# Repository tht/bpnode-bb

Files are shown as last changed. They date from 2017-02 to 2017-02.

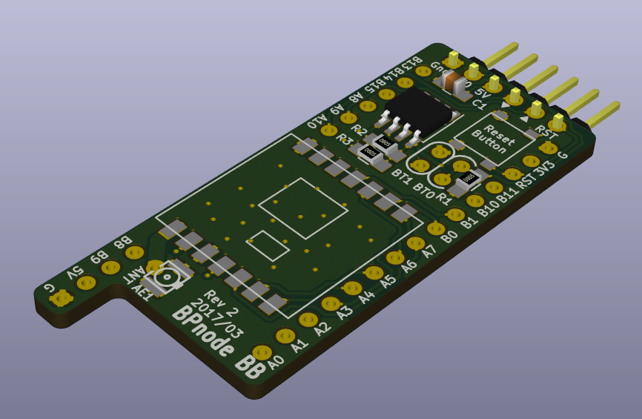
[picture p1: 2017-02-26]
images/rev1_top.png

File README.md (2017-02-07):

# *Blue Pill* Extender

There is a cheap, wildly available STTM3232F103C8T6 board out there. Because of it's shape and color it's called *Blue Pill* (BP). More details about this board can be found on [jeelabs](http://jeelabs.org/article/1649a/). There are *at least* two slightly different boards out there. This extension board is designed to match the BPs where the 2x03 pin header is next to `B11`, `B10` and `B1`. These are the boards where the USB connector is mounted in a cutout on the PCB. Other boards do have the USB connecter on top of the PCB and this 2x03 header is offset one pin – these boards will not fit nicely and need *creative* soldering as [shown here](https://cloud.githubusercontent.com/assets/148955/22704867/965d2520-ed69-11e6-9ae8-8ece3ff3e735.jpg).

The BP fits perfectly fine in a breadboard but it's missing the convenient programming headers for [SER+](http://jeelabs.org/article/1649f/) and some other features (see list below).

Thanks to the fantastic people over at jeelabs.org I was able to create this add-on board for the *Blue Pill* in KiCAD. This is how it will look like mounted on a BP.
BPE Mounted on a BP

## Features

* Programming header for programming the BP using a [SER+](http://jeelabs.org/article/1649f/) - including automatic reset of the target (BP)
* Area for mounting an RFM69-CW module
* Reset button
* Optimized for use on a breadboard

## Current State

Revision 1 is a little bit off-center but working perfectly fine.

There are some plans for the next revision of the board (see *Issues*). Some of them will probably become a completely different board as this one is meant to be used on a breadboard.

## Usage
The *Blue Pill Extender* (BPE) is mounted on top of an existing BP (label facing up). Make sure you solder the headers facing down to the BP first so it will fit into a breadboard before continuing here.

First prepare the BPE by soldering on the small resistors. The reset button is not required but may be helpful. Also add the RF module if you plan to use one. Make sure the RF module is not placed wrongly!

The 90° programming headers should be mounted from below (soldering on top) but they do work both ways.

Now remove the jumpers from the *BOOT?* pins on the BP and push the BPE on there. Make sure the 2x3 header of the *BOOT?* goes through the BPE and there there is still enough room to plug in an USB cable. Solder the 2x3 headers to the BPE. Now use some short wires (or leftover resistor legs) to connect all the outer BPE pins to the corresponding pins on the BP below – **DO NOT solder the antenna to the BP below!**

## References

* [Ser+ Programming Header](http://jeelabs.org/article/1649f/)
* [RFM69 CW Pinout](https://openenergymonitor.org/emon/sites/default/files/RFM69CW-V1.1_Hope_pinouts.jpg)
* [HyTiny Extender Layout](https://github.com/jeelabs/embello/blob/master/explore/1608-forth/tex/tex-v0.pdf)
* [BP Pinout](http://wiki.stm32duino.com/images/a/ae/Bluepillpinout.gif)

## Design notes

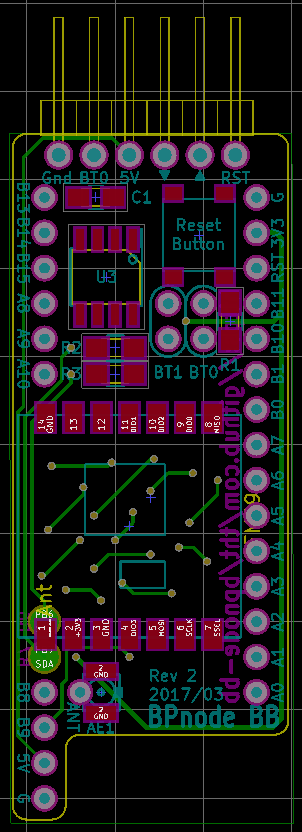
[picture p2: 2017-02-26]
images/rev1_board.png

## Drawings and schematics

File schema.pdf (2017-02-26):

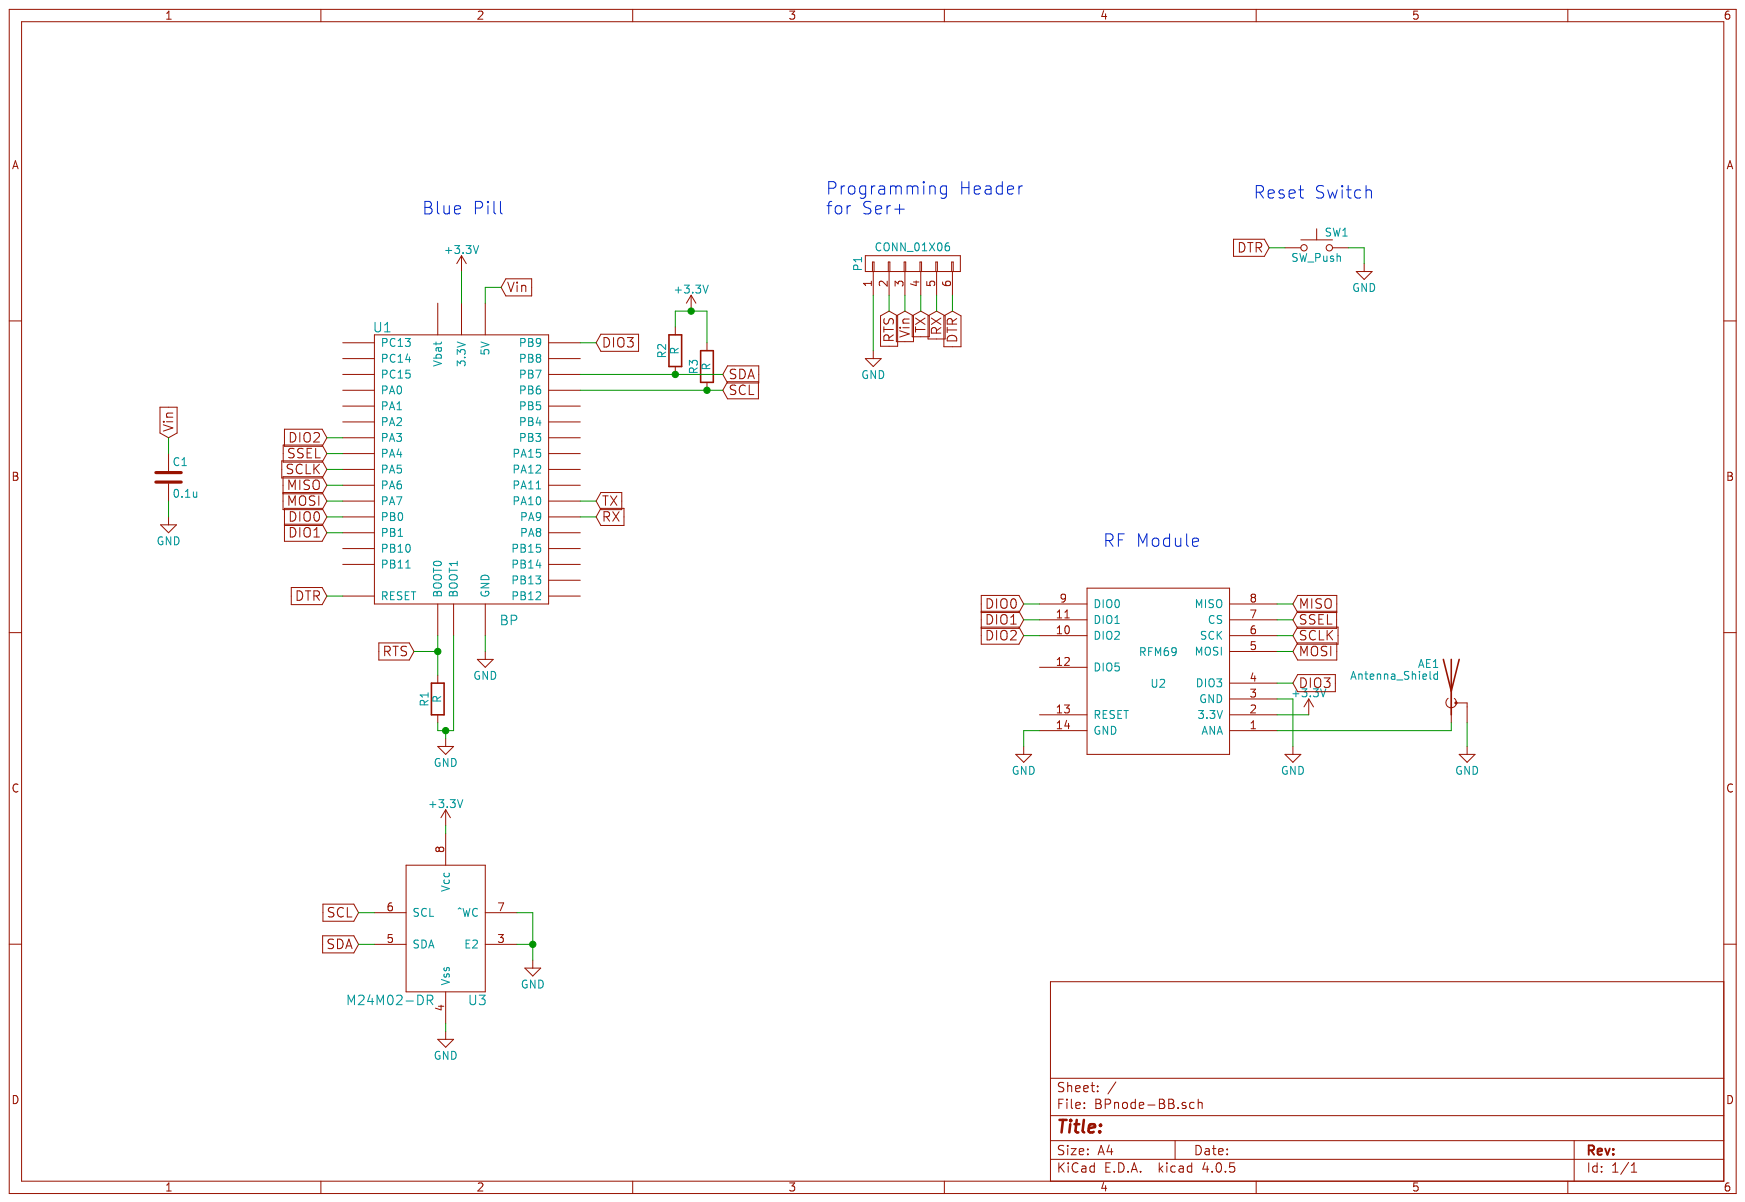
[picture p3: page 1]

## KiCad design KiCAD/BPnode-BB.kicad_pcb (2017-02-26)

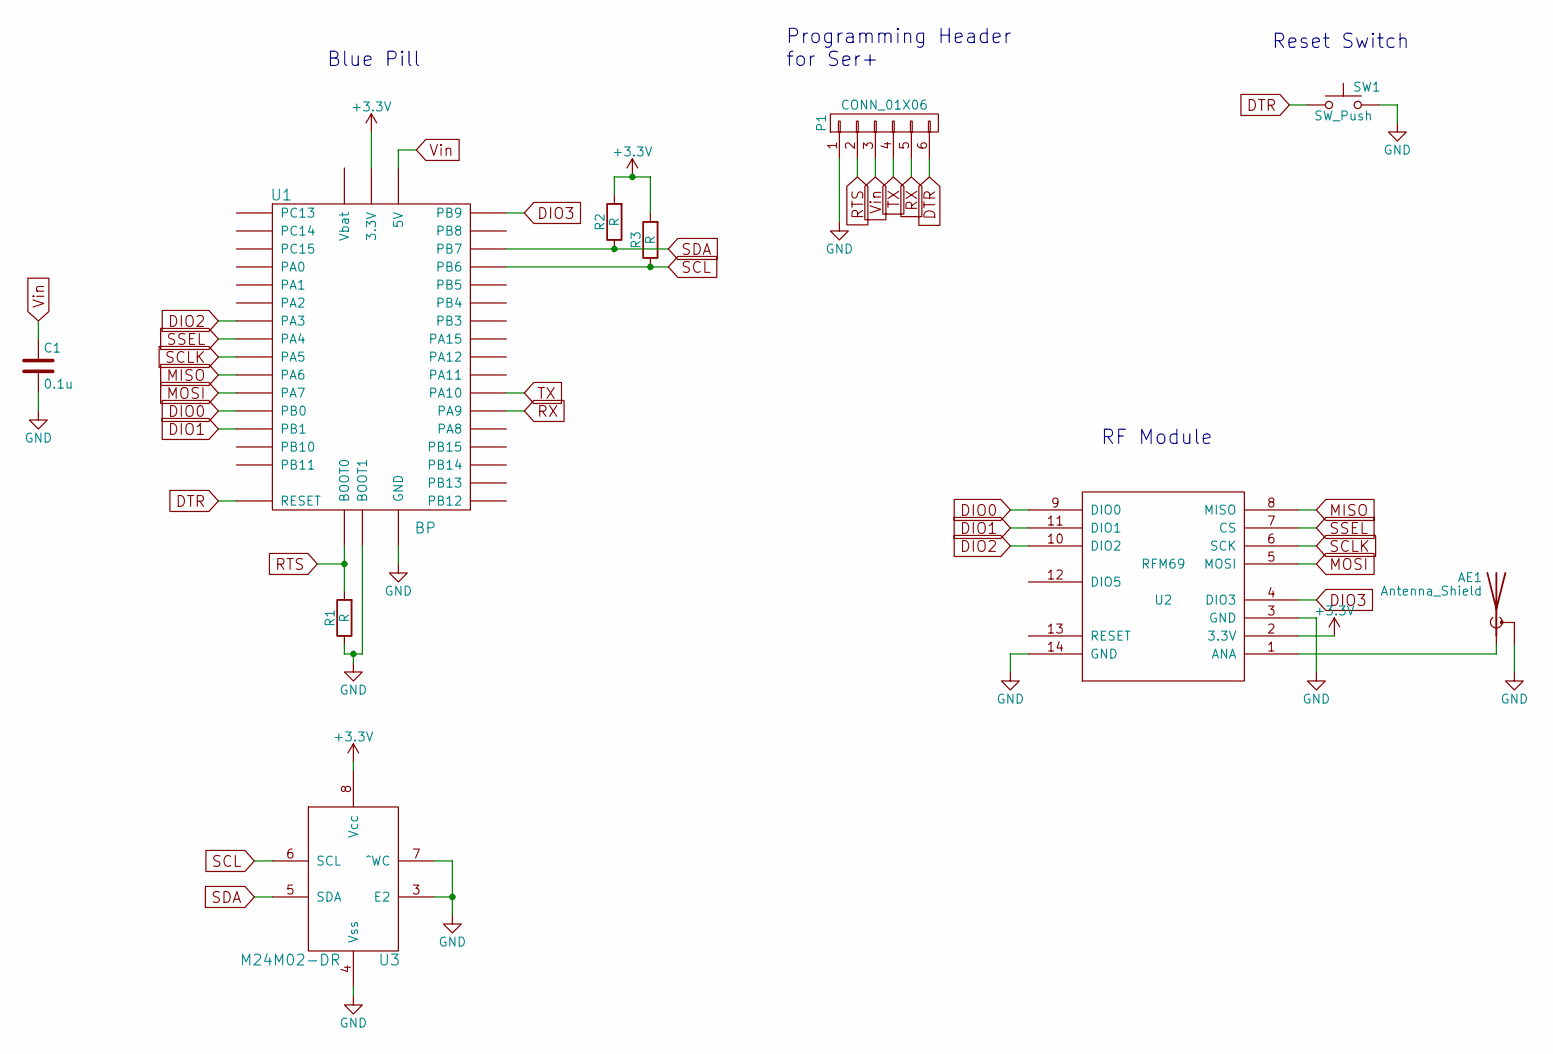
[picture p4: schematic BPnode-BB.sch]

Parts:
AE1: Antenna_Shield; U.FL-COAX
C1: 0.1u; C_0805_HandSoldering
P1: CONN_01X06; Pin_Header_Angled_1x06_Pitch2.54mm
R1, R2, R3: R; R_0805_HandSoldering
SW1: SW_Push; SMD_BUTTON
U1: BP; BLUEPILL-EXTENSION
U2: RFM69; RFM69CW
U3: M24M02-DR; SOIC-8_3.9x4.9mm_Pitch1.27mm

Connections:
+3V3: R2.2, R3.2, U1.3V3 (3.3V), U2.2 (3.3V), U3.8 (Vcc)
DIO0: U1.PB0, U2.9 (DIO0)
DIO1: U1.PB1, U2.11 (DIO1)
DIO2: U1.PA3, U2.10 (DIO2)
DIO3: U1.PB9, U2.4 (DIO3)
DTR: P1.6, SW1.1, U1.NRST (RESET)
GND: AE1.2 (Shield), C1.2, P1.1, R1.1, SW1.2, U1.G (GND), U1.PB2 (BOOT1), U2.3 (GND), U2.14 (GND), U3.3 (E2), U3.4 (Vss), U3.7 (^WC)
MISO: U1.PA6, U2.8 (MISO)
MOSI: U1.PA7, U2.5 (MOSI)
unnamed: AE1.1 (A), U2.1 (ANA)
RTS: P1.2, R1.2, U1.BOOT (BOOT0)
RX: P1.5, U1.PA9
SCL: R3.1, U1.PB6, U3.6 (SCL)
SCLK: U1.PA5, U2.6 (SCK)
SDA: R2.1, U1.PB7, U3.5 (SDA)
SSEL: U1.PA4, U2.7 (CS)
TX: P1.4, U1.PA10
Vin: C1.1, P1.3, U1.5V

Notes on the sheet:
RF Module
Reset Switch
Programming Header for Ser+
Blue Pill

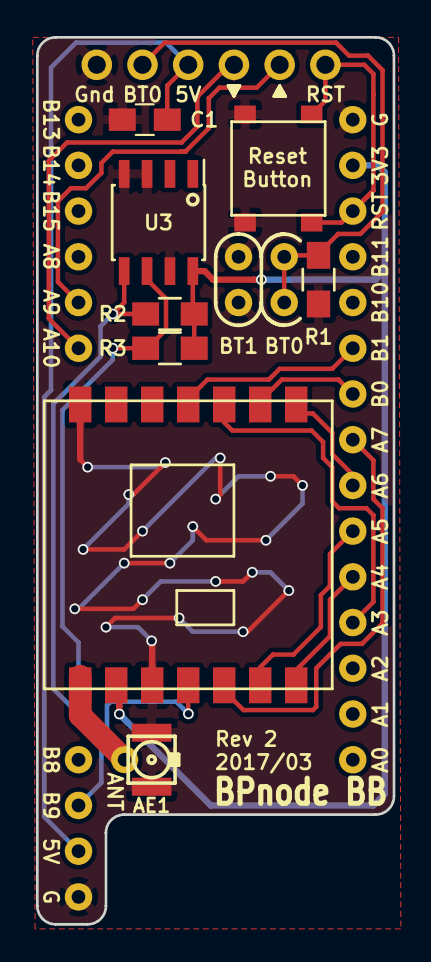
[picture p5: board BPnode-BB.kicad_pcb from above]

Board: 2 copper layers, 19.8 x 49.3 mm, 10 parts (0 on the bottom side), 18 nets.

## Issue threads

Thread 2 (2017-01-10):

Allow BP to reset the RFM69 module

tht, 2017-01-10:
Needs an additional pin, maybe some pull-up/down - unclear...

JohnOH, 2017-01-10:
Consider implications of using the STM reset pin.

Consider implications of detecting STM software reset since the STM Reset pin is pulled somewhere on software reset. I would be nice to have a latching LED if software reset happened. Pressing hardware reset would not set the LED, it would reset the latch.

JohnOH, 2017-01-12:
7.2.2. Manual Reset
A manual reset of the SX1231H is possible even for applications in which VDD cannot be physically disconnected. Pin 6 should be pulled high for a hundred microseconds, and then released. The user should then wait for 5 ms before using the chip.

Note whilst pin 6 is driven high, an over current consumption of up to ten milliamps can be seen on VDD.

JohnOH, 2017-01-17:
RESET on RFM is active high (ridiculous) - I can't tie them together

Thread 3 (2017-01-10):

Add a single AA boost chip / LDO regulator

JohnOH, 2017-01-10:
BP is a nice size for AA battery operation.
The existing regulator on the BP is frowned upon as being inefficient.

JohnOH, 2017-01-10:
Perhaps a LiPo charger instead, to act as  a UPS for an AC connected device.

tht, 2017-01-11:
The current *extender* is designed to be used on a breadboard. For standalone use there are some different requirements. For example we don't have to be on top of the BP and the size (specially the width) does not matter that much.

If this board works, we should start to collect requirements for another module - optimized for standalone use. AA power, LiPo charger and also easily accessible SPI and I2C ports are perfect candidates. I'll add a *label* to make sure de don't loose these ideas.

tht, 2017-02-09:
I will close this issue for now as this board has a different use-case and the BP is not optimized for low-power (battery) operation.

Closed 2017-02-09.

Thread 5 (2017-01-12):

Add a SPI Flash chip

JohnOH, 2017-01-12:
Similar to HyTiny extender. Other STM32 boards I have use a Winbond W25X16 which is 2M byte.

JohnOH, 2017-01-31:
Perhaps i2c rather than SPI to keep the radio clear.

tht, 2017-02-11:
Have you a recommendation for a commonly used I2C flash chip? My chunk drawer only *offers* some 5V devices…
I'll probably have to live on the back side of the board.

JohnOH, 2017-02-11:
I am not at home this weekend, I guess the 16Mb chip on the Jeelink would be a contender.

tht, 2017-02-11:
That's a Micron M25P16 SPI (0.80€ each). Looks like there aren't any I2C devices available with this capacity. The biggest one I could find is the STM M24M02 with 2Mbit for about 2.80€ each. So we have to decide between a 2Mbit I2C and a 16Mbit SPI. The board area does not allow for both.
Do you have a specific use-case in mind for this flash module?

Enjoy your day off!

JohnOH, 2017-02-11:
I imagined using it in a similar manner to the eeprom in the ATMega. I realise that a flash driver could be built (in C) but the cycle count is an order of magnitude less. The STM board I offer to you has an SPI eeprom on it, a W25X16. I was however concerned using SPI as my current approach in RFxConsole involves a scan of eeprom with each received pack as I store details of each node on the network. I don't know if SPI competition would be a problem.

JohnOH, 2017-02-11:
I also think that @jcw is on the i2c route for eeprom.

JohnOH, 2017-02-11:
Rereading everything, 2MB is more than enough for my currently perceived *needs*. Also, I thought you considered eeprom to be out of scope for this board.

tht, 2017-02-11:
Thanks for your feedback John. For me the small board size has priority but if there is a way to squeeze one mir IC on there, I'll do it.
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
As you can see the board area is not an issue. But now we need access to PB6 und PB7 for I2C. These pins are (of course) where the RF69 module is. I could add a smd solder pad on the bottom side where the RFM module is. I think this should still be possible to solder onto.

tht, 2017-02-11:
This is how it could work.
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
The small hole next to the SMD pads is the antenna connector. I'll move this one away when adding the U.FL connector.

jcw, 2017-02-11:
EEPROM mem over I2C is an order of magnitude slower compared to SPI flash. The F103 48-pin chip has 2 SPI buses, although that means more I/O pins needed, and IMO two devices on SPI is not that hard to support (even with interrupts: you can disable the ones from the radio while accessing flash).

FWIW, I want to drop flash again in the next HyTiny Extender revision - plan is to keep all persistent data on the USB host side. I guess it all depends on your use case.

Most flash chips are compatible, in terms of pinout. Would suggest using a _wide_ SIOC-8 footprint (5.3 mm), I think the narrow ones (3.9 mm) are starting to be phased out, definitely in larger sizes.

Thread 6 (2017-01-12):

Review CTS/DTR pin selection on FTDI interface

JohnOH, 2017-01-12:
If extender was mounted under the BP we have the option to collect the 4 pin group carrying GND/DCLK/DIO/3v3 in order to use DCLK & DIO similarly to HyTiny extender - see below:
https://github.com/jeelabs/embello/issues/35
This approach supports all the programming options via the FTDI port.

Extender on top would mean light pipes or holes to the see the LEDs - possible.

JohnOH, 2017-01-12:
Excessive enthusiasm on my part. The pin-out for a SER+ should be as above but the pin-in for a JNZ or similar needs to use BOOT0 and Reset.

JohnOH, 2017-01-14:
Review is still desirable since the FTDI port appears **able** to support the BMP firmware. The RX/TX and GND look good - not so sure about the DTR/CTS driving pins and their match to the *standard* BMP image. The 5v needs care to make sure it goes via a regulator on the target or is not activativated.

JohnOH, 2017-01-14:
Looks like these are the BMP pins:
TARGETBOARD     JC66_COREBOARD
 GND             GND
 SWDIO           PA4  *
 SWCLK           PA5  *
 POWER           3.3V from someplace with a common ground. Probably easiest to plug both boards in to USB

tht, 2017-02-09:
There are some good tutorials for converting a BP into a BMP ([hackaday](https://hackaday.io/project/19238-convert-stm32f103-board-to-a-black-magic-probe)).

For the moment this extension board is for BPs used as a programming *target* on a breadboard. IMHO this kinda conflicts with this issue and I don't want to include complicated parts like light pipes only to get the LEDs back.

Do I miss something here? Do you have a specific use-case?

JohnOH, 2017-02-09:
np, and thanks for the hackaday link.

JohnOH, 2017-02-11:
I appreciate that this board can operate as a node, subordinate to a Ser+ using its FTDI interface. I guess it can't operate as a Ser+ because of the choices made with regard to DTR and CTS/RTS.

I may be losing the plot here.

JohnOH, 2017-02-11:
Ser+ uses the SWD pins which are available on the tail end of the BP. Could use the two SWD pins to drive the DTR/RTS pins on a target node. TXD/RXD still derived from the FTDI header.

Closed 2017-02-09.

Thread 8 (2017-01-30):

Fix offset of rev1 board

tht, 2017-01-30:
The board is off-center – looks like 1.27mm. Should be fixed in rev2.

jcw, 2017-02-07:
There seem to be slightly different variants of the BP out there, see images.

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

JohnOH, 2017-02-07:
I think you may have a red pill layout on a blue PCB. I note that the USB connector is surface mounted rather than through the board. See http://www.stm32duino.com/viewtopic.php?t=117

JohnOH, 2017-02-07:
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

I fourteen units bought in two or three at a time from various chinese sources. They all have the the USB shield attached through the PCB rather than surface mount only.

tht, 2017-02-07:
Same here… about 10 boards, bought from two different sellers. All do have the USB socket mounted through the board. So this is the big difference, good to know. Thanks for investigating this issue. I will add a note in the `README.md`.

jcw, 2017-02-07:
Just to understand: my impression is that there is no difference, apart from appearance/dimensions?

jcw, 2017-02-07:
As I mentioned to Thomas in a private chat, I'm going to call mine the "twist and shout" setup - but it needs a lot of twisting and shouting to set up :) - haven't tried it out yet, it'll probably be 100% fine.

tht, 2017-02-07:
Your's is the one with *personality* :)

There are quite a few differences on these two boards. Labels are different, the USB connector is mounted different and the 2x03 header is not at the same place on the board. I think the board itself should be the same dimension when looking at your pictures. According to http://www.stm32duino.com/viewtopic.php?t=117 there is more like different LDOs and resistor/cap values.

JohnOH, 2017-02-08:
Perhaps we could physically remove four outer pins from the Blue Pill 2x03 header retaining only the path to the relevant GPIO pins. We could then drive these pins with 3v/GND derived from elsewhere on the Expander PCB. This would offer the opportunity of having four holes passing through the expander with connections in parallel such that a Red Pill and a Blue pill could both use the expander PCB soldering the appropriate two pins for that particular board.

tht, 2017-02-09:
Thats a great idea John. I'll most likely go this way for rev2 of the board. So it *should* fit on top of all red- and blue pills in red and blue coats.

3.3V and GND are available right next to these pins, so no problem to get these levels from other pins.

Only disadvantage is the loss in rigidity but I don't think this is a big issue. I will also try to Get hold of some long pin headers. Just snip off the top of these long headers where there is no hole in the extender board and connect all the others through.

tht, 2017-02-11:
I still have to fix the reset button's footprint and check if it's possible to add an U.FL connector but the offset *should* be fixed and this one is compatible with *pills* in all different colours.
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
I've added some holes which aren't absolutely needed. This should make it easier to mount it on extra long headers pushed through the BP and this adds-on board.

Closed 2017-02-11.

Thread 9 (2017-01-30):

Review reset button

tht, 2017-01-30:
The footprint is not compatible with the buttons I have. Review the footprint (or get other buttons)

Closed 2017-02-11.

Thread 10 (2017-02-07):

add diode in reset line from Ser+

tht, 2017-02-07:
Looks like it's working perfectly fine but there should be a diode in the reset line to make sure the BP is always able to do a clean reset.

jcw, 2017-02-07:
To clarify, although maybe it does not apply exactly to F103: on L052, a diode was needed to make reset 5V-tolerant and to support software reset, which cause the reset pin to be pulled low internally and act as an open-collector output. When tied to a stiff "1" logic level, software reset will fail.

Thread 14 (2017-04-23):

Rev2 PCB micro tweak

JohnOH, 2017-04-23:
Great work Thomas. I have only noticed one thing, based on a sample of one I think that the BT0/BT1 block could move half a millimetre closer to your reset switch to make the fit perfect. The same effect can be had by slightly bending the centre pair of BT0/BT1 pins a couple of degrees towards the processor. I don't have any Red Pill units and therefore can't comment on the implications there.

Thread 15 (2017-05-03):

I2C Eeprom Chip Enable

JohnOH, 2017-05-03:
E1 is unterminated and E2 is grounded. Since unterminated defaults to low the chip enable address bits are both 0.

JohnOH, 2017-05-05:
The *correct* datasheet only uses E2 as a chip enable.

Closed 2017-05-29.

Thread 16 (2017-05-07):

Access to BT0

JohnOH, 2017-05-07:
Ran into a problem whereby STLink, Black Magic Probe and Ser+/folie could not take control while running the STM32duino bootloader and [this](https://github.com/JChristensen/extEEPROM/tree/master/examples/eepromTest) sketch. Suspect code problems when running on STM32.

I needed to use BT0 to 33v3 to get back in control of the node. Used a jumper wire to the BT0 hole assigned to Red-Pill.

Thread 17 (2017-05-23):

Pull down resistor for BT1

JohnOH, 2017-05-23:
BT1 has significance in the STM32duino world as a mechanism to trigger perpetual bootloader. The general case of a high impedance pulldown on BT1 is flipped to 3v3 to enable the perpetual bootloader feature.

Currently we have a hard pull down to GND which precludes pulling to 3v3.

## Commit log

2017-01-09 Initial commit of board
    [BP-Extension.kicad_pcb, BP-Extension.sch]
2017-01-09 Ordered 2016_01_09
    [bp_ext.GBL, bp_ext.GBO, bp_ext.GBS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]
2017-02-07 Added note about different boards
2017-02-07 Moved 2x03 header to get rid of the offset, #8
    [BP-Extension.kicad_pcb, BP-Extension.sch]
2017-02-11 Almost ready for rev2. fixes #9, fixes #8, fixes #1
    [BP-Extension.kicad_pcb, BP-Extension.sch]
2017-02-18 Removed unnecessary files
    [BP-Extension.kicad_pcb]
2017-02-18 On the way to rev2
    [BP-Extension.kicad_pcb, BP-Extension.sch]
2017-02-19 Ready for ordering
    [BPnode-BB.kicad_pcb, BPnode-BB.sch]
2017-02-26 Rev 2 as ordered
    [BPnode-BB.kicad_pcb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]
